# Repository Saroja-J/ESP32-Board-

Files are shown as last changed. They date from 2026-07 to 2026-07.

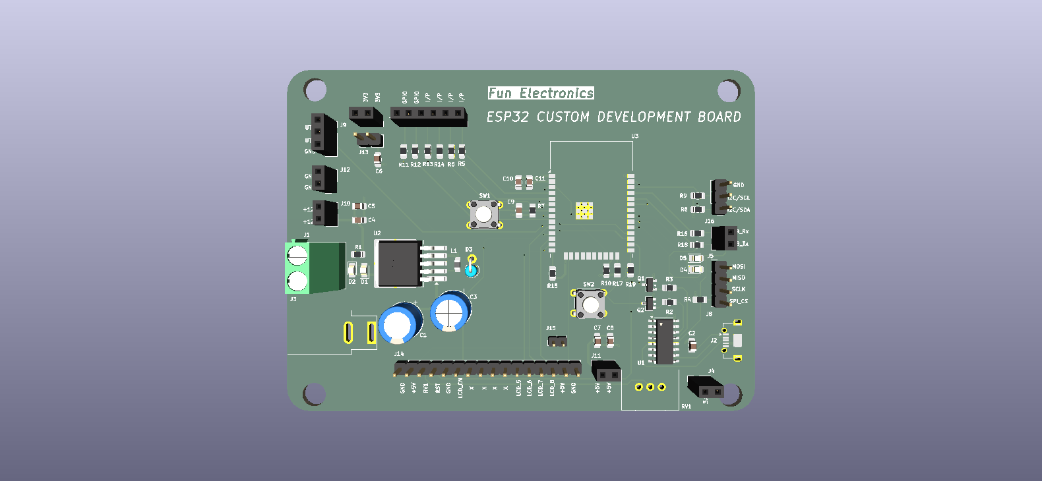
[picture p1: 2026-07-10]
4_Layer PCB/Images/top view.png

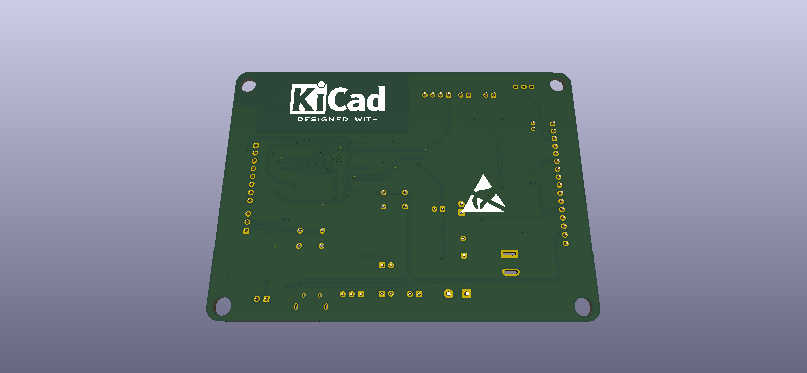
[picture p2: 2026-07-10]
2_layer PCB/Images/Img1.png

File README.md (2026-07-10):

# 📡 ESP32-WROOM-32D Development Board

A custom **ESP32-WROOM-32D Development Board** designed in **KiCad** for IoT and embedded applications. The board integrates USB-to-UART programming, power management, automatic reset and boot circuitry, and GPIO expansion, providing a compact platform for developing Wi-Fi and Bluetooth-enabled systems.

---

## 📖 Overview

This project is based on the **ESP32-WROOM-32D**, a Wi-Fi and Bluetooth-enabled microcontroller module from Espressif. The board includes a **CH340C USB-to-UART interface**, **LM2596 buck converter**, automatic reset and boot circuitry, GPIO headers, and supporting passive components. It supports **UART, SPI, I²C, PWM, ADC, and GPIO** interfaces, making it suitable for IoT, embedded systems, automation, and rapid prototyping.

---

## 📷 PCB Layout Images

> Add your PCB images below.

| 2-Layer PCB | 4-Layer PCB |
|---|---|
|  | |

---

## ⚙️ Working

1. The board is powered through USB or an external power source.
2. The **LM2596 buck converter** provides a regulated power supply for the board.
3. The **CH340C** enables USB-to-UART communication for programming and serial debugging.
4. The automatic **Reset** and **Boot** circuit allows easy firmware uploading.
5. After programming, the ESP32 communicates with external peripherals through its GPIO and communication interfaces.

---

## ✨ Features

-  ESP32-WROOM-32D Wi-Fi & Bluetooth Module
-  CH340C USB-to-UART Interface
-  LM2596 Buck Converter
-  Automatic Reset & Boot Circuit
-  GPIO Expansion Headers
-  Supports UART, SPI, I²C, PWM & ADC
-  Designed using KiCad

---

## 🛠️ Components

| Component | Description |
|---|---|
| ESP32-WROOM-32D | Main Wi-Fi & Bluetooth microcontroller |
| CH340C | USB-to-UART programming interface |
| LM2596 | Buck converter for power regulation |
| USB Connector | Power input and programming |
| NPN Transistors | Automatic Reset & Boot switching |
| Push Buttons | Manual Reset & Boot |
| Capacitors | Power filtering and decoupling |
| Resistors | Pull-up, pull-down and current limiting |
| GPIO Headers | External peripheral connections |

---

## 🚀 Applications

- 🌐 Internet of Things (IoT)
- 🏠 Home Automation
- 🤖 Robotics
- 📡 Wireless Sensor Nodes
- 📊 Data Logging
- 🎛️ Embedded System Development

---

## 📐 Design Details

- Designed by referring to the **ESP32-WROOM-32D Datasheet**, **Hardware Design Guidelines**, and supporting component datasheets.
- Recommended resistor and capacitor values were used throughout the design.
- Decoupling capacitors were placed close to the ESP32 power pins for stable operation.
- A copper-free keep-out zone was maintained around the ESP32 antenna for better RF performance.
- NPN transistors were used for the automatic **Reset** and **Boot** switching circuit.
- The **4-layer PCB** uses copper-filled planes for improved power distribution and grounding.
- Both the **2-layer** and **4-layer** PCB designs were completed with **0 DRC errors**.
- The **LM2596** buck converter was designed using its datasheet. For different input voltages or output currents, refer to the datasheet to select the appropriate inductor and capacitor values.
- An **ESD protection diode** recommended in the ESP32 Hardware Design Guidelines is **not included** in this revision and can be added in future designs.

---

## ⚠️ Warning

This design does **not** include an **ESD protection diode** on the **3.3V supply** near the **ESP32-WROOM-32D**, although it is recommended in the **ESP32 Hardware Design Guidelines**. It can be added in future revisions to improve protection against electrostatic discharge (ESD).

---

## 📄 License

This project is shared for **educational and learning purposes**.

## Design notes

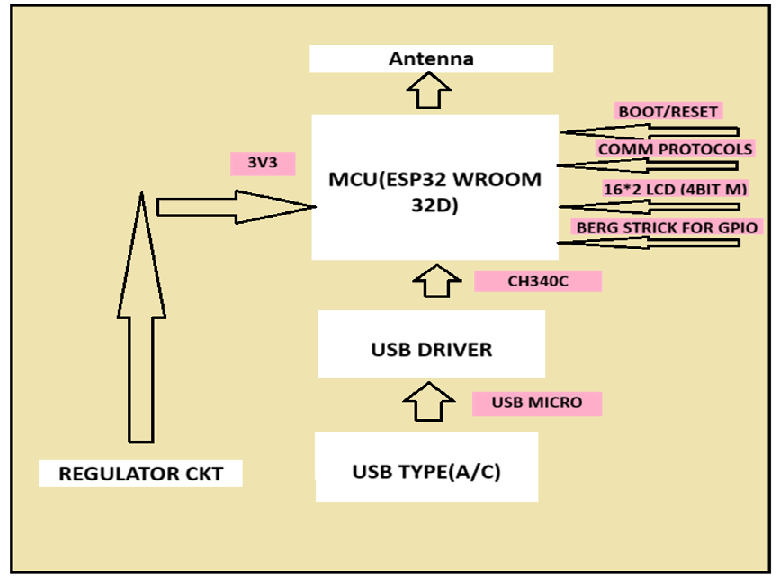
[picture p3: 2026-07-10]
2_layer PCB/Images/Architecture.png

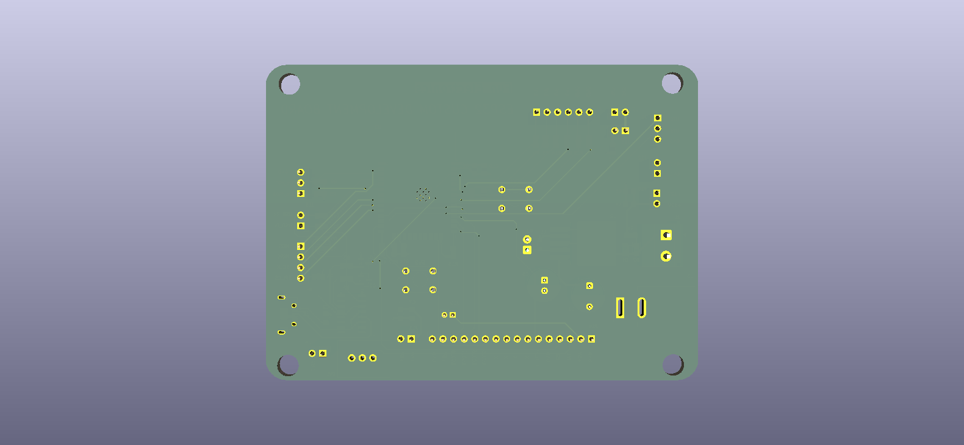
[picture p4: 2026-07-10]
4_Layer PCB/Images/bottom_view.png

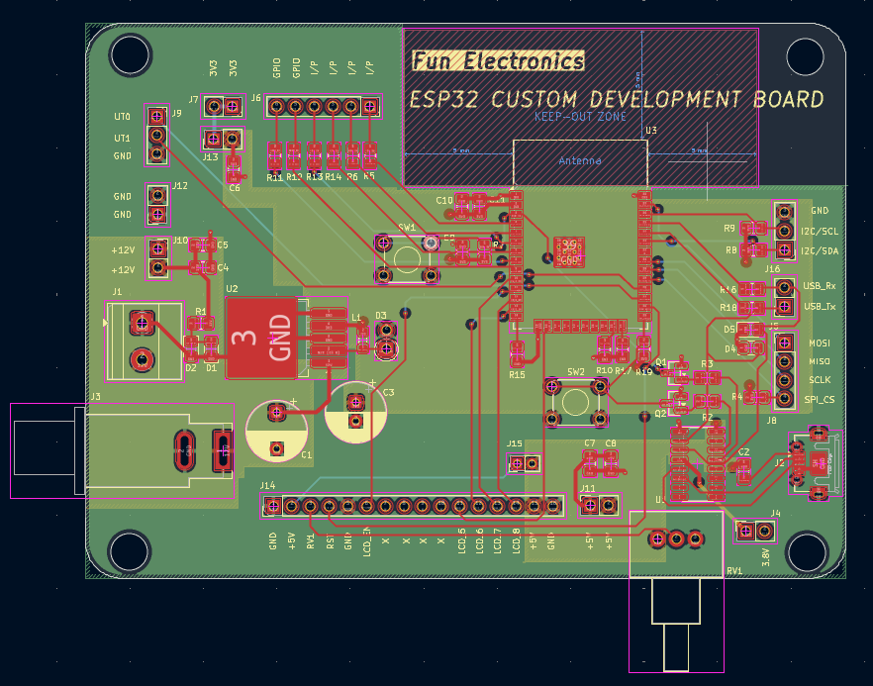
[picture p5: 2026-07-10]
4_Layer PCB/Images/layout.png

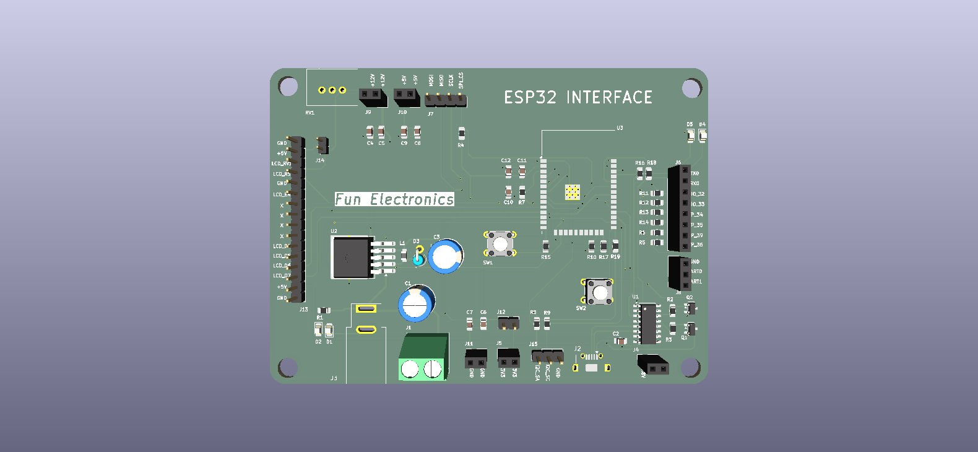
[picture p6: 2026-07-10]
2_layer PCB/Images/Top_view.png

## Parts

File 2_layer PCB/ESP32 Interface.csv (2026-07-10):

Reference | Qty | Value | DNP | Exclude from BOM | Exclude from Board | Footprint | Datasheet
C1 | 1 | 680/35V |  |  |  | Capacitor_THT:CP_Radial_D8.0mm_P5.00mm
C2,C5,C6,C7,C8,C9 | 6 | C |  |  |  | Capacitor_SMD:C_0805_2012Metric_Pad1.18x1.45mm_HandSolder
C3 | 1 | 220uF/16V |  |  |  | Capacitor_THT:CP_Radial_D8.0mm_P2.50mm
C4,C10,C11 | 3 | 0.1uF |  |  |  | Capacitor_SMD:C_0805_2012Metric_Pad1.18x1.45mm_HandSolder
C12 | 1 | 10uF |  |  |  | Capacitor_SMD:C_0805_2012Metric_Pad1.18x1.45mm_HandSolder
D1 | 1 | RED |  |  |  | LED_SMD:LED_0805_2012Metric_Pad1.15x1.40mm_HandSolder
D2 | 1 | YELLOW |  |  |  | LED_SMD:LED_0805_2012Metric_Pad1.15x1.40mm_HandSolder
D3 | 1 | SM518 |  |  |  | Diode_THT:D_T-1_P2.54mm_Vertical_AnodeUp | http://cdn-reichelt.de/documents/datenblatt/A400/SMD1N400%23DIO.pdf
D4 | 1 | GREEN |  |  |  | LED_SMD:LED_0805_2012Metric_Pad1.15x1.40mm_HandSolder
D5 | 1 | BLUE |  |  |  | LED_SMD:LED_0805_2012Metric_Pad1.15x1.40mm_HandSolder
J1 | 1 | Screw_Terminal_01x02 |  |  |  | TerminalBlock_Phoenix:TerminalBlock_Phoenix_MKDS-1,5-2-5.08_1x02_P5.08mm_Horizontal
J2 | 1 | USB_B_Micro |  |  |  | Connector_USB:USB_Micro-AB_Molex_47590-0001
J3 | 1 | Jack-DC |  |  |  | Connector_BarrelJack:BarrelJack_SwitchcraftConxall_RAPC10U_Horizontal
J4 | 1 | Conn_01x02_Socket |  |  |  | Connector_PinSocket_2.54mm:PinSocket_1x02_P2.54mm_Vertical
J5,J9,J10,J11 | 4 | Conn_01x02_Pin |  |  |  | Connector_PinSocket_2.54mm:PinSocket_1x02_P2.54mm_Vertical
J6 | 1 | Conn_01x08_Pin |  |  |  | Connector_PinSocket_2.54mm:PinSocket_1x08_P2.54mm_Vertical
J7 | 1 | Conn_01x04_Pin |  |  |  | Connector_PinHeader_2.54mm:PinHeader_1x04_P2.54mm_Vertical
J8 | 1 | Conn_01x03_Pin |  |  |  | Connector_PinSocket_2.54mm:PinSocket_1x03_P2.54mm_Vertical
J12 | 1 | Conn_01x02_Socket |  |  |  | Connector_PinHeader_2.54mm:PinHeader_1x02_P2.54mm_Vertical
J13 | 1 | Conn_01x16_Pin |  |  |  | Connector_PinHeader_2.54mm:PinHeader_1x16_P2.54mm_Vertical
J14 | 1 | Conn_01x02_Socket |  |  |  | Connector_PinHeader_2.00mm:PinHeader_1x02_P2.00mm_Vertical
J15 | 1 | Conn_01x03_Pin |  |  |  | Connector_PinHeader_2.54mm:PinHeader_1x03_P2.54mm_Vertical
L1 | 1 | 33uH |  |  |  | Inductor_SMD:L_0805_2012Metric_Pad1.05x1.20mm_HandSolder
Q1,Q2 | 2 | MMBT2222A |  |  |  | Package_TO_SOT_SMD:SOT-23 | https://assets.nexperia.com/documents/data-sheet/MMBT2222A.pdf
R1 | 1 | 2.7K |  |  |  | Resistor_SMD:R_0805_2012Metric_Pad1.20x1.40mm_HandSolder
R2,R3,R4,R7,R8,R9,R10,R15,R17,R18,R19 | 11 | 10k |  |  |  | Resistor_SMD:R_0805_2012Metric_Pad1.20x1.40mm_HandSolder
R5,R6,R11,R12,R13,R14 | 6 | 330 |  |  |  | Resistor_SMD:R_0805_2012Metric_Pad1.20x1.40mm_HandSolder
R16 | 1 | 470 |  |  |  | Resistor_SMD:R_0805_2012Metric_Pad1.20x1.40mm_HandSolder
RV1 | 1 | R_Potentiometer |  |  |  | Potentiometer_THT:Potentiometer_Vishay_148-149_Single_Horizontal
SW1,SW2 | 2 | SW_Omron_B3FS |  |  |  | Button_Switch_THT:SW_TH_Tactile_Omron_B3F-100x | https://omronfs.omron.com/en_US/ecb/products/pdf/en-b3fs.pdf
U1 | 1 | CH340C |  |  |  | Package_SO:SOIC-16_3.9x9.9mm_P1.27mm | https://datasheet.lcsc.com/szlcsc/Jiangsu-Qin-Heng-CH340C_C84681.pdf
U2 | 1 | LM2596S-3.3 |  |  |  | Package_TO_SOT_SMD:TO-263-5_TabPin3 | http://www.ti.com/lit/ds/symlink/lm2596.pdf
U3 | 1 | ESP32-WROOM-32D |  |  |  | RF_Module:ESP32-WROOM-32D | https://www.espressif.com/sites/default/files/documentation/esp32-wroom-32d_esp32-wroom-32u_datasheet_en.pdf

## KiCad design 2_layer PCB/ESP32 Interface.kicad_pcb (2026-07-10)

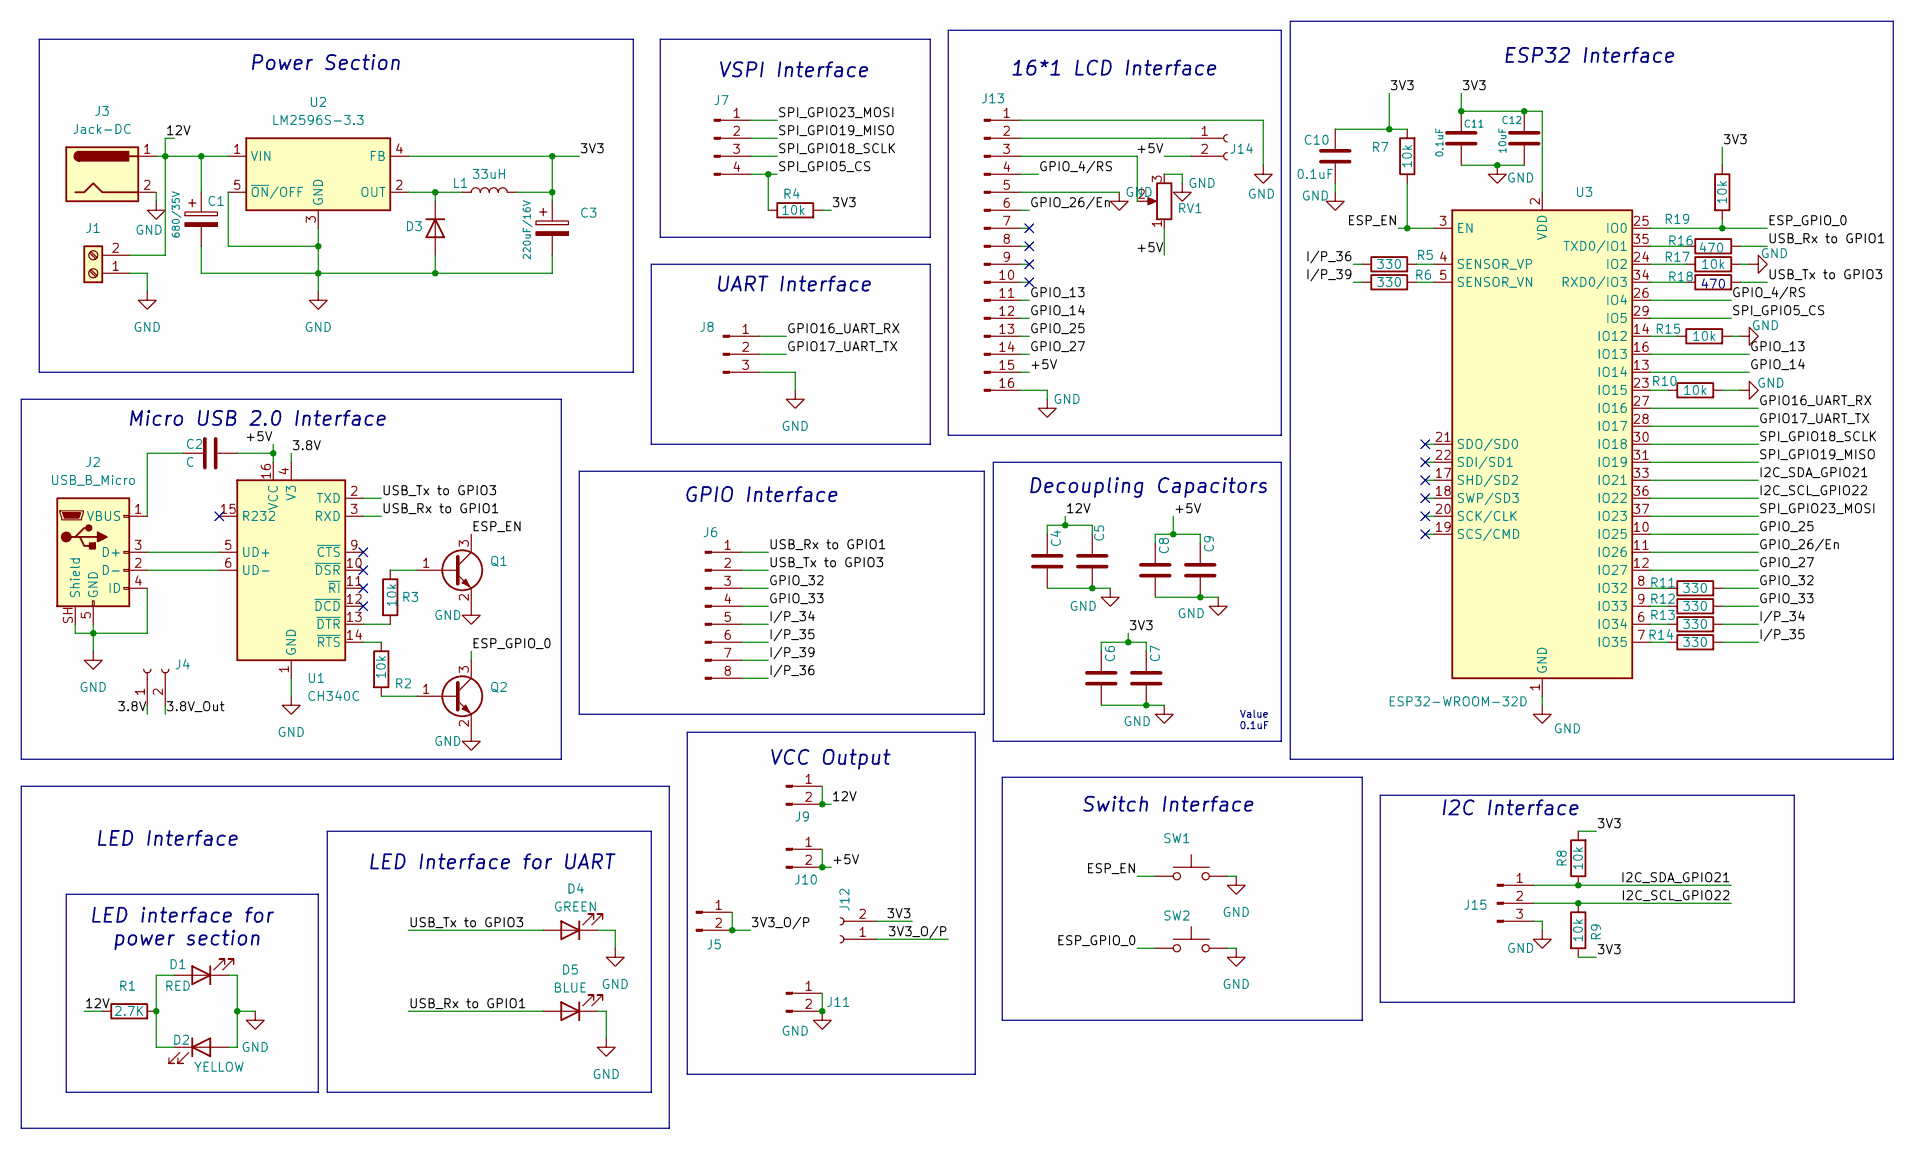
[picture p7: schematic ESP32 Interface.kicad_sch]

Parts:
C1: 680/35V; CP_Radial_D8.0mm_P5.00mm
C2, C5, C6, C7, C8, C9: C; C_0805_2012Metric_Pad1.18x1.45mm_HandSolder
C3: 220uF/16V; CP_Radial_D8.0mm_P2.50mm
C4, C10, C11: 0.1uF; C_0805_2012Metric_Pad1.18x1.45mm_HandSolder
C12: 10uF; C_0805_2012Metric_Pad1.18x1.45mm_HandSolder
D1: RED; LED_0805_2012Metric_Pad1.15x1.40mm_HandSolder
D2: YELLOW; LED_0805_2012Metric_Pad1.15x1.40mm_HandSolder
D3: SM518; D_T-1_P2.54mm_Vertical_AnodeUp
D4: GREEN; LED_0805_2012Metric_Pad1.15x1.40mm_HandSolder
D5: BLUE; LED_0805_2012Metric_Pad1.15x1.40mm_HandSolder
J1: Screw_Terminal_01x02; TerminalBlock_Phoenix_MKDS-1,5-2-5.08_1x02_P5.08mm_Horizont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
J2: USB_B_Micro; USB_Micro-AB_Molex_47590-0001
J3: Jack-DC; BarrelJack_SwitchcraftConxall_RAPC10U_Horizontal
J4: Conn_01x02_Socket; PinSocket_1x02_P2.54mm_Vertical
J5, J9, J10, J11: Conn_01x02_Pin; PinSocket_1x02_P2.54mm_Vertical
J6: Conn_01x08_Pin; PinSocket_1x08_P2.54mm_Vertical
J7: Conn_01x04_Pin; PinHeader_1x04_P2.54mm_Vertical
J8: Conn_01x03_Pin; PinSocket_1x03_P2.54mm_Vertical
J12: Conn_01x02_Socket; PinHeader_1x02_P2.54mm_Vertical
J13: Conn_01x16_Pin; PinHeader_1x16_P2.54mm_Vertical
J14: Conn_01x02_Socket; PinHeader_1x02_P2.00mm_Vertical
J15: Conn_01x03_Pin; PinHeader_1x03_P2.54mm_Vertical
L1: 33uH; L_0805_2012Metric_Pad1.05x1.20mm_HandSolder
Q1, Q2: MMBT2222A; SOT-23
R1: 2.7K; R_0805_2012Metric_Pad1.20x1.40mm_HandSolder
R2, R3, R4, R7, R8, R9, R10, R15, R17, R18, R19: 10k; R_0805_2012Metric_Pad1.20x1.40mm_HandSolder
R5, R6, R11, R12, R13, R14: 330; R_0805_2012Metric_Pad1.20x1.40mm_HandSolder
R16: 470; R_0805_2012Metric_Pad1.20x1.40mm_HandSolder
RV1: R_Potentiometer; Potentiometer_Vishay_148-149_Single_Horizontal
SW1, SW2: SW_Omron_B3FS; SW_TH_Tactile_Omron_B3F-100x
U1: CH340C; SOIC-16_3.9x9.9mm_P1.27mm
U2: LM2596S-3.3; TO-263-5_TabPin3
U3: ESP32-WROOM-32D

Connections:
/3.8V: J4.1, U1.4 (V3)
/3.8V_Out: J4.2
/3V3: C3.1, C6.2, C7.2, C10.1, C11.1, C12.1, J12.2, L1.2, R4.2, R7.2, R8.2, R9.2, R19.1, U2.4 (FB), U3.2 (VDD)
/3V3_O/P: J5.1, J5.2, J12.1
/12V: C1.1, C4.2, C5.2, J1.2, J3.1, J9.1, J9.2, R1.1, U2.1 (VIN)
/+5V: C2.1, C8.2, C9.2, J10.1, J10.2, J13.15, J14.2, RV1.1, U1.16 (VCC)
/ESP_EN: Q1.3 (C), R7.1, SW1.1, U3.3 (EN)
/ESP_GPIO_0: Q2.3 (C), R19.2, SW2.1, U3.25 (IO0)
/GPIO16_UART_RX: J8.1, U3.27 (IO16)
/GPIO17_UART_TX: J8.2, U3.28 (IO17)
/GPIO_4/RS: J13.4, U3.26 (IO4)
/GPIO_13: J13.11, U3.16 (IO13)
/GPIO_14: J13.12, U3.13 (IO14)
/GPIO_25: J13.13, U3.10 (IO25)
/GPIO_26/En: J13.6, U3.11 (IO26)
/GPIO_27: J13.14, U3.12 (IO27)
/GPIO_32: J6.3, R11.2
/GPIO_33: J6.4, R12.2
/I2C_SCL_GPIO22: J15.2, R9.1, U3.36 (IO22)
/I2C_SDA_GPIO21: J15.1, R8.1, U3.33 (IO21)
/I/P_34: J6.5, R13.2
/I/P_35: J6.6, R14.2
/I/P_36: J6.8, R5.1
/I/P_39: J6.7, R6.1
/SPI_GPIO5_CS: J7.4, R4.1, U3.29 (IO5)
/SPI_GPIO18_SCLK: J7.3, U3.30 (IO18)
/SPI_GPIO19_MISO: J7.2, U3.31 (IO19)
/SPI_GPIO23_MOSI: J7.1, U3.37 (IO23)
/USB_Rx to GPIO1: D5.2 (A), J6.1, R16.2, U1.3 (RXD)
/USB_Tx to GPIO3: D4.2 (A), J6.2, R18.2, U1.2 (TXD)
GND: C1.2, C3.2, C4.1, C5.1, C6.1, C7.1, C8.1, C9.1, C10.2, C11.2, C12.2, D1.1 (K), D2.2 (A), D3.2 (A), D4.1 (K), D5.1 (K), J1.1, J2.4 (ID), J2.5 (GND), J2.SH (Shield), J3.2, J8.3, J11.1, J11.2, J13.1, J13.5, J13.16, J15.3, Q1.2 (E), Q2.2 (E), R10.2, R15.2, R17.2, RV1.3, SW1.2, SW2.2, U1.1 (GND), U2.3 (GND), U2.5 (~ON/OFF), U3.1 (GND), U3.15 (GND), U3.38 (GND), U3.39 (GND)
unnamed: D1.2 (A), D2.1 (K), R1.2
unnamed: D3.1 (K), L1.1, U2.2 (OUT)
unnamed: J2.3 (D+), U1.5 (UD+)
unnamed: J2.2 (D-), U1.6 (UD-)
unnamed: C2.2, J2.1 (VBUS)
unnamed: J13.2, J14.1
unnamed: J13.3, RV1.2
unnamed: Q1.1 (B), R3.1
unnamed: Q2.1 (B), R2.2
unnamed: R3.2, U1.13 (~DTR)
unnamed: R2.1, U1.14 (~RTS)
unnamed: R17.1, U3.24 (IO2)
unnamed: R15.1, U3.14 (IO12)
unnamed: R10.1, U3.23 (IO15)
unnamed: R11.1, U3.8 (IO32)
unnamed: R12.1, U3.9 (IO33)
unnamed: R13.1, U3.6 (IO34)
unnamed: R14.1, U3.7 (IO35)
unnamed: R18.1, U3.34 (RXD0/IO3)
unnamed: R6.2, U3.5 (SENSOR_VN)
unnamed: R5.2, U3.4 (SENSOR_VP)
unnamed: R16.1, U3.35 (TXD0/IO1)

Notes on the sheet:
Micro USB 2.0 Interface
16*1 LCD Interface
Switch Interface
UART Interface
I2C Interface
LED interface for power section
LED Interface
ESP32 Interface
Value 0.1uF
Power Section
Decoupling Capacitors
GPIO Interface
VSPI Interface
470
VCC Output
LED Interface for UART

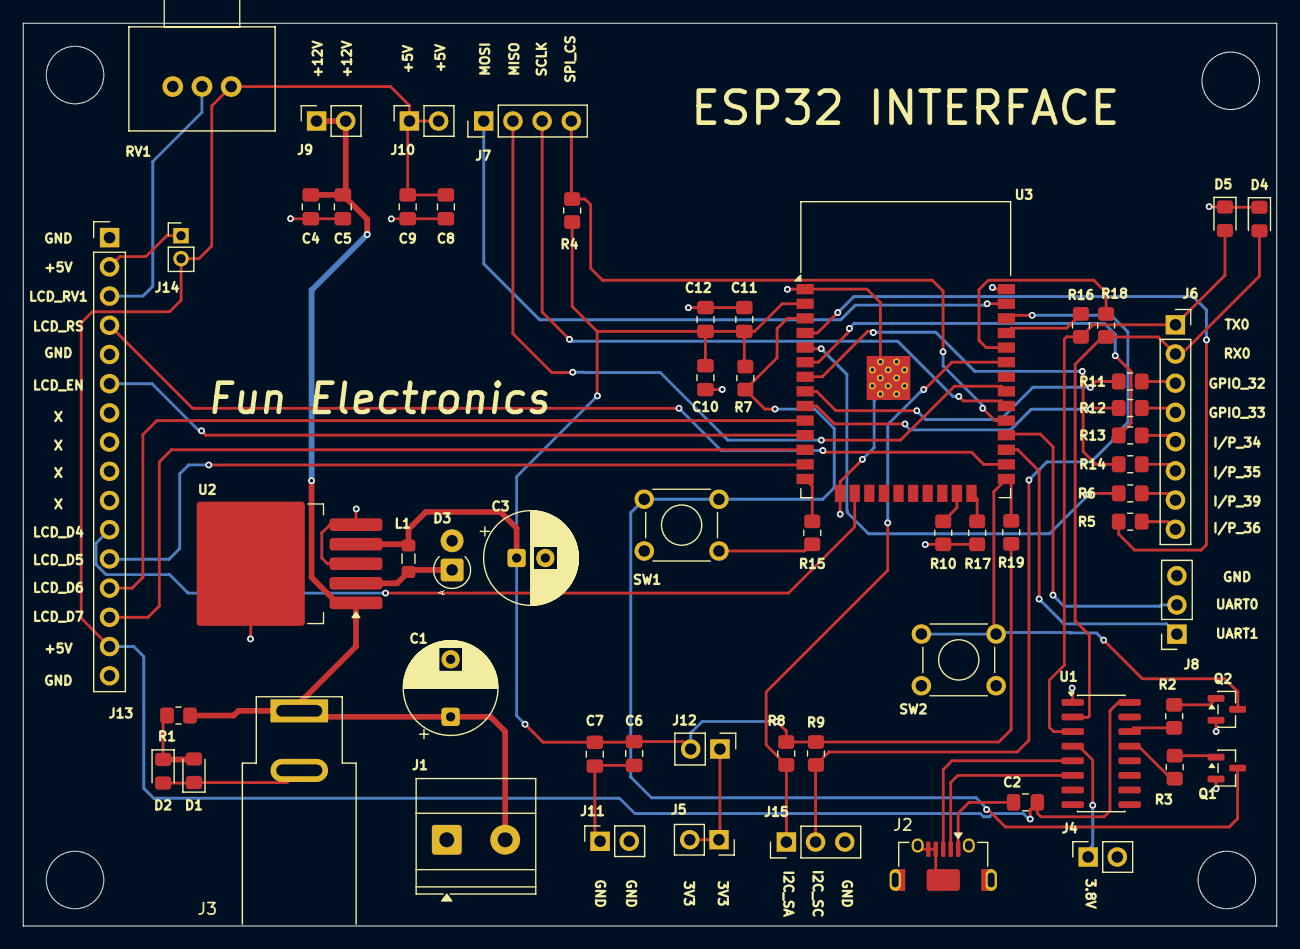
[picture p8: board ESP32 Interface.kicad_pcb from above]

Board: 2 copper layers, 109.0 x 78.5 mm, 60 parts (0 on the bottom side), 52 nets.
